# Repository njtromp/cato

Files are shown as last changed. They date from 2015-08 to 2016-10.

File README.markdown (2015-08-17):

# What's it all about
This project started slightly after I bought a sail boat, an Amigo 27 to be precisely.
At the time I bought the boat I did notice that the log (speed indicator) was not working
but that didn't bother me much. There where much, more important things, that needed my
attention. It is a mechanical VDO SumLog. There where two reasons for the log not to function.

1. a broken inner cable
2. a rusted impeller that does not turn

These two causes combined with the fact that replacement parts are hard to get your hands on
and the fact that I had a spare GPS Bluetooth dongle started me thinking. What if I can use
the GPS dongle for determining the speed and have a small (like a Raspberry PI) computer
control a electronic motor that drives the speed gauge?

## From RPM to knots and visa versa
I run some experiments using a cordless screwdriver for determining the RPM/knots settings.
It turned out to be about 100 RPM per knot :-). 

# Components
I needed some different components to get everything working

## Hardware
* a small computer
* a Bluetooth GPS dongle
* a USB Bluetooth dongle, for connecting the GPS to the computer
* a motor control unit that is capable of driving the electronic motor
* a electronic motor that is capable of runnning at 800-900 RPM with enough torque that will
be attached to the remainder of the inner cable
* a speed sensor for determining the RPM of the electronic motor (needed for feedback loop)

After some Googling and browsing the internet I come to the following shoppinglist:

* a Raspberry PI B+ (small, low power consumption, 4 USB ports, capable of running Debian)
* a small Bluetooth dongle
* a powerfull electro motor (capble of running at 13000 RPM and a torque of about 0.15 Nm)
* a AdaFruit PWM board based upon a PCA9685 chip
* a power mosfet that will be driven by the AdaFruit board and that will drive the engine
* a good old power transistor 2N3055 and a 12V zener-diode that will ensure that the voltage that
is supplied to the electro motor will stay constant and within the allowed range
* a IR photomicrosensor that can be used for detecting the RPM of the electro motor

I also bought a USB WiFi dongle that will be used for providing a small local WiFi network.  

## Software
* a program that reads the speed information from the GPS dongle and adjusts the speed of
the electronic motor

Although I am a Java Software Engineer by trade I wanted to use a language that has a smaller
memory footprint. After experimenting with Python and NodeJS I chose NodeJS. There are a
lot of modules available for it that integrate with GPSD for example. An other thing that I
like is the fact that the JavaScript is compiled to native code by the V8 engine prior to
running the code.

# Putting it all together
Back in highschool I played a lot around with electronic components and used a soldering iron
for repairing TVs, radios etc. so with I little luck I should still be able to get the
hardware connected. The software proved to be quite easy although being used to a statically
typed language is challenging a loosely typed language needs more trial and error then I am
used to. After some experimenting and using the soldering iron after 25 years I had a prototype
that seemed to be working. During the first trials I discovered that the electro motor was
having a difficult time working at low speeds, typically below 200-300 RPM.

## First improvements (dual power setting)
The problems at low RPMs are caused by the low duty-cycle of the PWM. In order to get the
duty-cycle up the engine must run using a lower voltage. Because I already was using a very
simple voltage stabilizing component (the 2N3055 and the zener-diode) it was relatively easy
to add a extra transistor and a second zener-diode (5V this time) to the existing voltage
stabilizing circuit. This change needed a software counterpart as well. The program must be
able to switch between the voltages at which the engine is running. In order to prevent the
system from switching back and forth between the two different power settings some sort of
delay was needed between the moment the first switch was needed and the actual switching.
The first trials with this new power switching module showed a flaw in the motorcontrol
program. When the power setting was switched from low voltage (5V) to high voltage (12V)
the engine initially was spinning at around 900 RPM (which is equal to 9 knots!) while
prior to the switch is was running at around 300 RPM. Within seconds this was corrected by
the feedback loop but it was not the behavior I wanted. Measuring the duty-cycle at low
voltage and high voltage with the some target RPM showed that there seems to be a 10 to 3
ratio between the duty-cycles. With the control program correcting the duty-cycle when
switching between the power settings lead to a small jitter that is for now within
acceptable ranges.  

## Second improvements (wireless instruments application)
As mentioned before I also bought a USB WiFi dongle. The purpose of this dongle is to have
the Raspberry PI act as a WiFi hotspot that should provide internet connection (through USB
tethering) to everybody on board as long as my phone as a proper internet connection.
Besides provinding internet access this lead to the idea of a small web application that
would use the GPS information for showing the speed and location on any connected device.

# Where to go next
Up till now everything seems to be working. Everything is still in beta phase but for me it
is working fine. Because I was not very familiar with NodeJS and used a whole lot of mixed
quality examples and made some wrong design decisions in the early stages of the project
the whole project needs a major overhaul.

## Code overhaul
* write my own NMEA handling/parsing. I haven't found a NodeJS module that handles NMEA
messages in a way I like (mind you that I am coming from a statically typed language).
* introduce a easier extensible software architecture (NMEA event bus)
* get rid of the tightly coupling between NMEA parsing, motor control, powerswitching and
the instruments application

# TODO
* add some pictures
* add some electronic diagrams
* log the NMEA message on the Raspberry PI for later usage by other applications, OpenCPN
for example

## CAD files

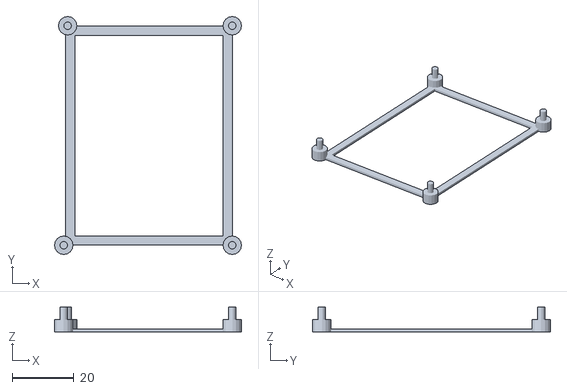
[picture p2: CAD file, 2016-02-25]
tinker/cato_log_controller_case.stl
60.6 x 77.1 x 8.00

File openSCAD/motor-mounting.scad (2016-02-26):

module raw_motor_support(width,depth,clearance,motorDiameter) {
	height = motorDiameter/2+clearance-0.5;
	difference() {
		cube([width,depth,height]);
		translate([width/2,0,motorDiameter/2+clearance]) {
			rotate([-90,0,0]) {
				$fn=64;
				cylinder(h=depth,d=motorDiameter);
			}
		}
	}
}

module nut_mount(nutDiameter,boltHeadDiameter,boltLength,boltDepth) {
	translate($fn=64,[0,0,boltDepth]) cylinder(boltLength, d=nutDiameter);
	cylinder($fn=6,boltDepth, d=boltHeadDiameter);
}

module bolt_mount(boltDiameter,boltHeadDiameter,boltLength,boltDepth) {
	$fn=64;
	translate([0,0,boltDepth]) cylinder(boltLength, d=boltDiameter);
	cylinder(boltDepth, d=boltHeadDiameter);
}

module upper_support() {
	difference() {
		raw_motor_support(width,depth,clearance,motorDiameter);
		translate([10,depth/2,0]) bolt_mount(boltDiameter+0.5,boltHeadDiameter+0.5,boltLength,boltDepth);
		translate([width-10,depth/2,0]) bolt_mount(boltDiameter+0.5,boltHeadDiameter+0.5,boltLength,boltDepth);
	}
}

module lower_support() {
	difference() {
		raw_motor_support(width,depth,clearance,motorDiameter);
		translate([10,depth/2,0]) nut_mount(boltDiameter+0.5,nutDiameter+0.5,boltLength,boltDepth);
		translate([width-10,depth/2,0]) nut_mount(boltDiameter+0.5,nutDiameter+0.5,boltLength,boltDepth);
	}
}

width=60;
depth=25;
clearance=10;
motorDiameter=32;
boltDiameter=3;
boltHeadDiameter=6;
nutDiameter=8;
boltLength=10;
boltDepth=motorDiameter/2+clearance-boltLength;

lower_support();
translate([width,0,motorDiameter +2*clearance]) rotate([0,180,0]) upper_support();

// difference(){
// 	translate([-2*clearance,-2*clearance,-clearance]) {
// 		cube([width+4*clearance,depth+4*clearance,clearance]);
// 	}
// }

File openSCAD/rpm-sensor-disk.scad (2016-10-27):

module pie_slice(thickness,innerRadius,outerRadius,angle) {
	$fn=64;
	difference() {
		intersection() {
			cylinder(h=thickness, r=outerRadius, center=false);
			cube([outerRadius,outerRadius,thickness],false);
	    	rotate(angle-90) cube([outerRadius,outerRadius,thickness],false);
		}
    	cylinder(h=thickness, r=innerRadius, center=false);
	}
}

module rpm_disk(thickness,axeRadius,nodgeIndent,outerRadius,innerRadius,wingCount) {
	$fn=30;
	// Create hole for axis
	difference() {
		cylinder(thickness, r=innerRadius);
		cylinder(thickness, r=axeRadius);
	}
	// Correction for nodge
	translate([axeRadius-nodgeIndent, -axeRadius, 0]) {
		cube([axeRadius, 2*axeRadius, thickness]);
	}

	// Place 'wings'
	for(angle = [0: 360/wingCount : 359]) {
		rotate(angle) {
			pie_slice(thickness,innerRadius-0.5,outerRadius,180/wingCount);
		}
	}
}

rpm_disk(3,3,0.5,20,10,6);

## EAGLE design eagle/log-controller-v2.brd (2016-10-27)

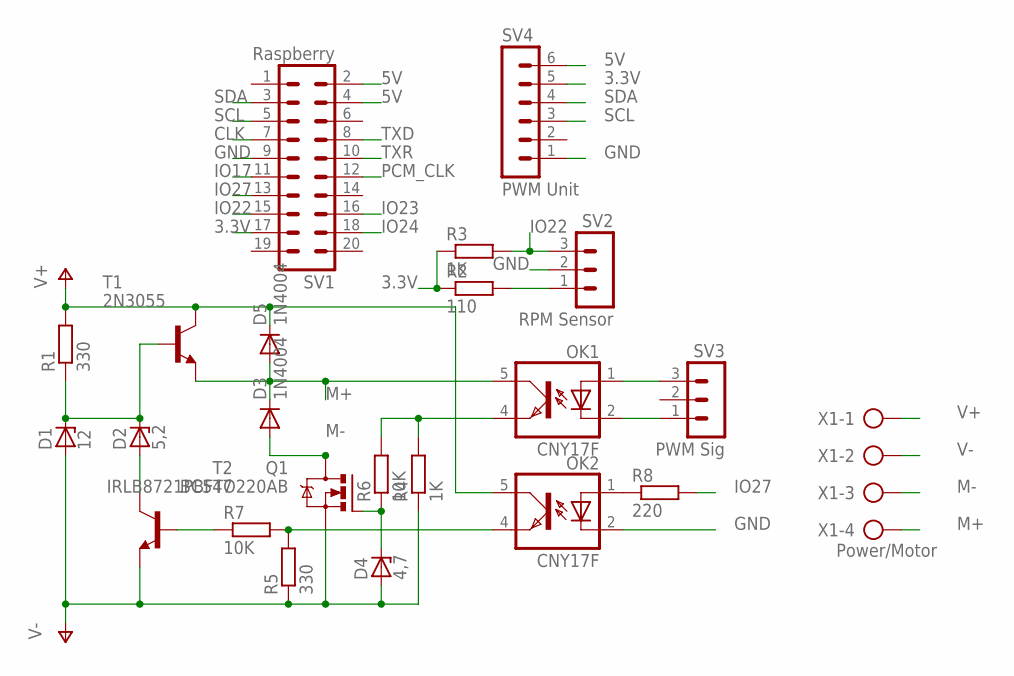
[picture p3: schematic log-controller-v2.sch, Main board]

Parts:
D1: 12; DO34Z7
D2: 5,2; DO34Z7
D3, D5: 1N4004; DO41-10
D4: 4,7; DO34Z7
OK1, OK2: CNY17F; DIL06
Q1: IRLB8721PBFTO220AB; TO220AB
R1, R5: 330; 0207/12
R2: 110; 0207/10
R3: 1K; 0207/10
R4: 1K; 0207/12
R6, R7: 10K; 0207/12
R8: 220; 0207/10
SV1: Raspberry; MA10-2
SV2: RPM Sensor; MA03-1
SV3: PWM Sig; MA03-1
SV4: PWM Unit; MA06-1
T1: 2N3055; TO3
T2: BC547; TO92
X1: Power/Motor; AK300/4

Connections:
3.3V: R2.1, R3.1, SV1.17, SV4.5
5V: SV1.2, SV1.4, SV4.6
CLK: SV1.7
GND: OK2.2 (C), SV1.9, SV2.2, SV4.1
IO17: SV1.11
IO22: R3.2, SV1.15, SV2.3
IO23: SV1.16
IO24: SV1.18
IO27: R8.2, SV1.13
M+: D3.C, D5.A, OK1.5 (COL), T1.E, X1.4
M-: D3.A, Q1.D, X1.3
unnamed: D1.C, D2.C, R1.1, T1.B
unnamed: D2.A, T2.3 (C)
unnamed: OK1.4 (EMIT), R4.2, R6.2
unnamed: R2.2, SV2.1
unnamed: OK1.1 (A), SV3.3
unnamed: OK1.2 (C), SV3.1
unnamed: OK2.4 (EMIT), R5.2, R7.2
unnamed: R7.1, T2.2 (B)
unnamed: D4.C, Q1.G, R6.1
unnamed: OK2.1 (A), R8.1
PCM_CLK: SV1.12
SCL: SV1.5, SV4.3
SDA: SV1.3, SV4.4
TXD: SV1.8
TXR: SV1.10
V+: D5.C, OK2.5 (COL), R1.2, T1.C, T1.C/ (C), X1.1
V-: D1.A, D4.A, Q1.S, R4.1, R5.1, T2.1 (E), X1.2

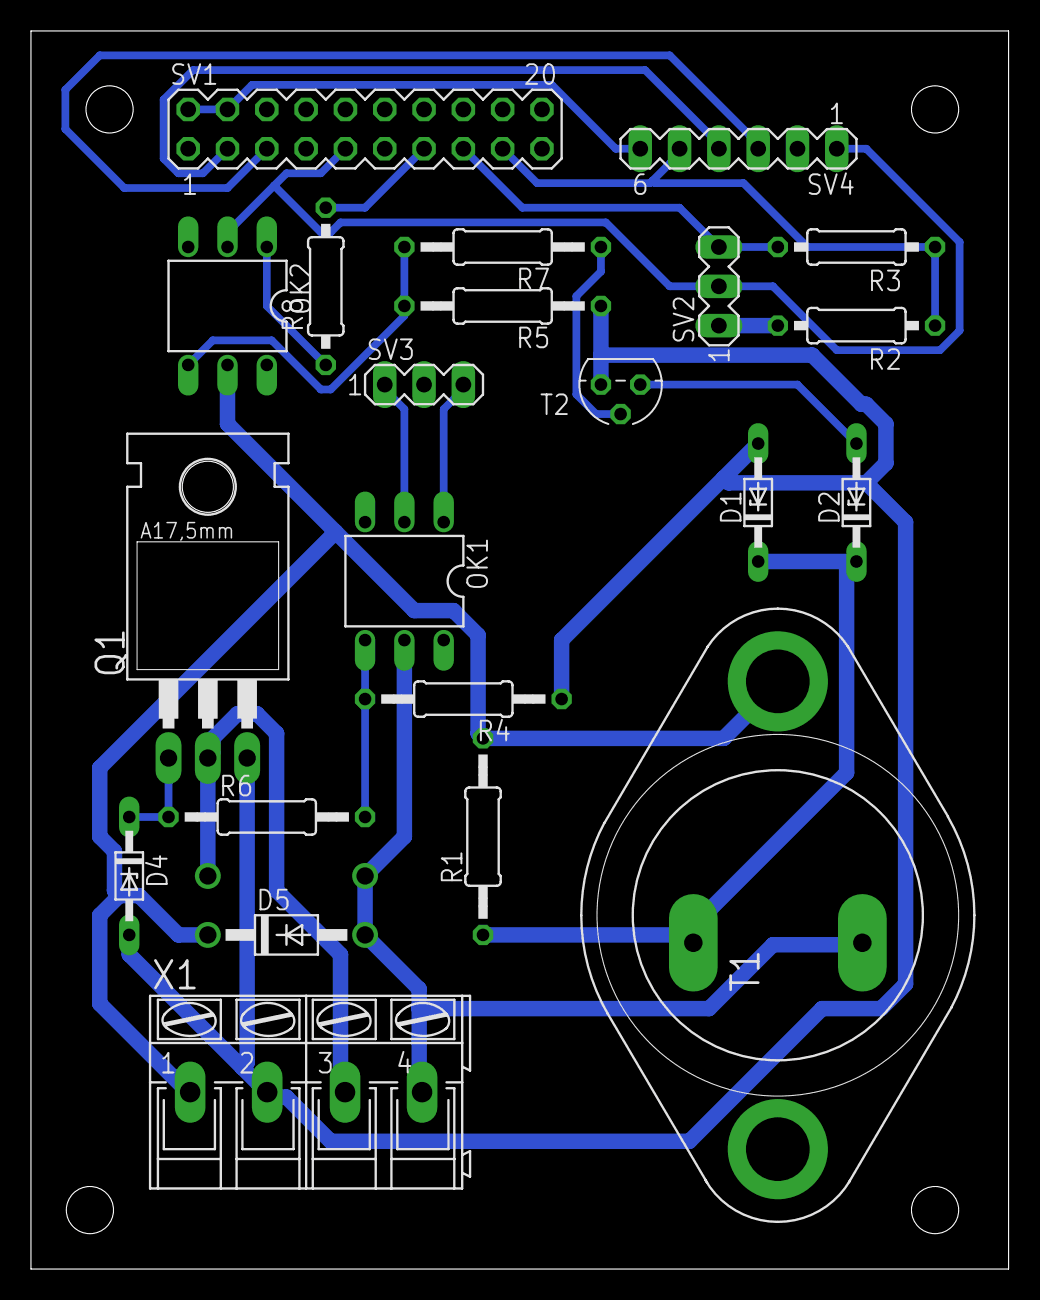
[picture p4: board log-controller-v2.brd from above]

Board: 2 copper layers, 63.2 x 80.0 mm, 23 parts (1 on the bottom side), 21 nets.

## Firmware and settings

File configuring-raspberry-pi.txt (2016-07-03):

# Configuring Raspberry PI

# Use the RasPI config tool to enable I2C and serial support
sudo raspi-config

# Basicaaly I followed this tutorial
# https://learn.adafruit.com/setting-up-a-raspberry-pi-as-a-wifi-access-point/install-software
# https://learn.adafruit.com/adafruit-ultimate-gps-on-the-raspberry-pi/setting-everything-up

# The next could be needed when starting the rasp-config tools complains about no language has been set
cat << 'EOF' >> /etc/default/locale
LANG=en_US.UTF-8
LANGUAGE=en_US.UTF-8
LC_ALL=en_US.UTF-8
EOF

# Here is the real installation :-)

# Install dnsmasq
sudo apt-get install dnsmasq

#Configure DNS DHCP (dnsmasq)
# Change or add to the bottom of the configuration fiel
cat << 'EOF' >> /etc/dnsmasq.conf
interface=eth0
interface=wlan0
no-hosts
addn-hosts=/etc/hosts.dnsmasq
dhcp-range=192.168.66.20,192.168.66.150,24h
dhcp-range=192.168.99.20,192.168.99.150,24h
dhcp-option=6,192.168.66.10
dhcp-option=6,192.168.99.10
EOF

# Make the Raspberry PI known on two differen names
cat << 'EOF' > /etc/hosts.dnsmasq
192.168.66.10 cato
192.168.99.10 cato-wired
EOF

# Install hostapd for Raspberry PI
sudo apt-get install hostapd

# Configure hostapd
# Configure the access point
cat << 'EOF' >> /etc/hostpad/hostapd.conf
# Basic configuration
interface=wlan0
ssid=cato
channel=6
hw_mode=g
country_code=NL

# WPA and WPA2 configuration
macaddr_acl=0
ignore_broadcast_ssid=0
wpa=2
wpa_passphrase=<dat mag je niet weten!>
wpa_key_mgmt=WPA-PSK
wpa_pairwise=CCMP
rsn_pairwise=CCMP
EOF

# Enable the accesspoint
cat << 'EOF' >> /etc/default/hostapd
DAEMON_CONF="/etc/hostapd/hostapd.conf"
EOF

# Enable forwarding in the kernel permanent
# sudo vi /etc/sysctl.conf
# Search near the end
# net.ipv4.ip_forward=1

# and for now
sudo sh -c "echo 1 > /proc/sys/net/ipv4/ip_forward"

# Configure the iptables
sudo iptables -t nat -A POSTROUTING -o usb0 -j MASQUERADE 
sudo iptables -A FORWARD -i usb0 -o wlan0 -m state --state RELATED,ESTABLISHED -j ACCEPT
sudo iptables -A FORWARD -i wlan0 -o usb0 -j ACCEPT
sudo iptables -A FORWARD -i usb0 -o eth0 -m state --state RELATED,ESTABLISHED -j ACCEPT
sudo iptables -A FORWARD -i eth0 -o usb0 -j ACCEPT
# Save the configuration
sudo sh -c "iptables-save > /etc/network/iptables.forward.nat"

# And activate the configuration after each reboot
cat << 'EOF' >> /etc/network/interfaces
up iptables-resotre < /etc/network/iptables.forward.nat
EOF

# Install GPSD daemon and some tools
sudo apt-get install gpsd gpsd-clients

# Remove 'console=ttyAMA0,115200' and 'kgdboc=ttyAMA0,115200' if present from /boot/cmdline.txt

# Disable some serial services
sudo systemctl mask serial-getty@ttyAMA0.service

# Create startup script for the gpsd service
cat << 'EOF' > start-gps
#!/bin/bash
sudo /usr/sbin/gpsd -n -G -F /var/run/gpsd.sock /dev/ttyAMA0
EOF
chmod +x start-gpsd
 
# Addd the next line to 'crontab -e'
@reboot /home/pi/start-gpsd

# Start the GPSD daemon
# -G listen on all interfaces
# -n don't wait for clients to connect (start polling the GPS immediately)
# gpsd -G -n /dev/ttyAMA0

# Check if everything is working properly (Optional)
# gpsmon /dev/ttyAMA0

# Enable i2c interface
sudo apt-get install i2c-tools

# Activate I2C modules and configuration
cat << 'EOF' >> /etc/modules
i2c-bcm2708 
i2c-dev
EOF

# Only if not present, so check first!
#cat << 'EOF' >> /boot/config.txt
#dtparam=i2c1=on
#dtparam=i2c_arm=on
#EOF

# Install nodejs
curl -sLS https://apt.adafruit.com/add | sudo bash
sudo apt-get install node
# This gives a segfault :-(
#curl -sL https://deb.nodesource.com/setup_6.x | sudo -E bash -
#sudo apt-get install nodejs

# The next lines might not be needed but unable to verify at this moment
#sudo apt-get install python-smbus
#sudo chmod o+rw /dev/i2c*

# The next lines might not be needed but unable to verify at this moment
# Only needed when running 'gcc' results in a 'unknown program/command'
# Version numbers might be different!
#sudo apt-get install gcc-4.8 g++-4.8
#sudo update-alternatives --install /usr/bin/gcc gcc /usr/bin/gcc-4.8 60 --slave /usr/bin/g++ g++ /usr/bin/g++-4.8
#sudo update-alternatives --install /usr/bin/gcc gcc /usr/bin/gcc-4.9 40 --slave /usr/bin/g++ g++ /usr/bin/g++-4.9
#sudo update-alternatives --config gcc 

# Install used modules
npm install node-gpsd onoff keypress socket.io nmea-0183
# Due to some error during building lets use a previous version
npm install i2c@0.2.1

# Install Apache HTTPD
sudo apt-get install apache2
sudo a2enmod proxy
sudo a2enmod proxy_http

# Add reverse proxy configuration after the last <Directory> element
# sudo vi /etc/apache2/sites-enabled/000-default
#        ProxyPass / http://cato:8080/ retry=0
#        ProxyPassReverse / http://cato:8080/ 
# And restart Apache
# sudo service apache2 restart

# Add the following line to 'crontab -e'
@reboot /home/pi/start-nodejs

# Create (sym)links to 'start-gpsd' and 'start-nodejs' in the home folder.

sudo reboot

# RPM 299, 5V  => Offstep = 1900
# RPM 301, 12V => Offstep = 565

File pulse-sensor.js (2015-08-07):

/**
 * This module measures the pulselength of a IR sensor that detects the rotation
 * of a disc (whith intermitted holes) that is attached to a electronic motor. 
 */

"use strict";

var Gpio = require('onoff').Gpio;

/**
 * Starts a new sensor. 
 *
 * @param: config has two properties.
 * - sensorPin: the GPIO pin number to which the pulse sensor is attached.
 * - activeLevel: the level (0 or 1) which is considered as the start of a new pulse. 
 *
 * @param: pulseCallback (optional) function is called on every pulse. This method takes a single
 * parameter that will have the value of the pulselength in nanoseconds of the last pulse.
 */
function PulseSensor(config, pulseCallback) {
  console.log('Installing RPM sensor listener.');
  this.pulseCallback = typeof pulseCallback === "function" ? pulseCallback : function(pulseLengthInNanos) { return; };
  this.sensorPin = config.sensorPin;
  this.activeLevel = config.activeLevel;
  this.lastSwitch = -1;
  this.pulses = new Array();
  
  this.sensor = new Gpio(config.sensorPin, 'in', 'both');
  var _this = this;
  this.sensor.watch(function(err, value) {
    _this.registerPulse(value)
  });
}

/**
 * Retuns the average pulse length of the pulses since the
 * last call to this function. The pulse length is in nanosecods.
 * A value of -1 indicates that no pulse has been detected since
 * the previous pulse!
 */
PulseSensor.prototype.getAveragePulseLength = function() {
  if (this.pulses.length == 0) {
    return -1;
  } else {
    var copyOfPulses = this.pulses.splice(0, this.pulses.length);
    return averagePulseLength(copyOfPulses);
  }
}

/**
 * Adds new pulse to the set of pulses and calls the pulseCallback function.
 */
PulseSensor.prototype.registerPulse = function(value) {
  if (value == this.activeLevel) {
    var currentSwitch = convertNanoTimeData(process.hrtime());
    if (this.lastSwitch != -1) {
      var pulseLengthInNanos = currentSwitch - this.lastSwitch;
      this.pulses.push(pulseLengthInNanos);
      this.pulseCallback(pulseLengthInNanos);
    }
    this.lastSwitch = currentSwitch;
  }
}

/**
 * Converts the nano-second time construct (from process.hrtime()) into a single value.
 */
function convertNanoTimeData(nanoTimeData) {
  return (nanoTimeData[0] * 1000000000) + nanoTimeData[1];
} 

/**
 * Returns the average pulse length of the pulses present in copyOfPulses.
 */
function averagePulseLength(copyOfPulses) {
  var sum = 0;
  for (var i = 0; i < copyOfPulses.length; i++) {
    sum += copyOfPulses[i];
  }
  return sum / copyOfPulses.length;
}

module.exports = PulseSensor;

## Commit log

2015-03-13 Switched to better structure of the code
2015-03-13 Added shutdown button via Node.js :-)
2015-03-14 Added jitter detection.
2015-03-18 Implementing own motor control. The PCA9685 module contains errors and has some timing issues that need to be handled.
2015-03-18 Looping through led dim cycle.
2015-03-29 Trying to switch to nano seconds....
2015-03-29 Using millseconds for RPM sensor.
2015-03-29 Displaying milliseconds for every 1/6th rotation.
2015-03-30 RPM sensor will be used by another module, not by Cato directly
2015-04-05 Refactored the motor and pwm modules.
2015-04-06 Sensor is working.
2015-04-07 Refactored code so the global THIS variable is no longer needed.
    [pulse-sensor.js]
2015-04-07 Tweaked motor control so it is able to drop the RPM till 100.
2015-04-07 Renamed motor to rpm-controller.
2015-04-08 Added calibration module.
2015-04-08 Scaffolding for calibration done.
2015-04-08 Calibration should be working.
2015-04-08 Restructed the calibration configuration.
2015-04-08 Switched to actual working version.
    The previous ones had some 'require' lines placed as comments.
2015-04-09 Fixed issues that prevented 'calibrate' not to function.
    [factory.js]
2015-04-17 Added some comment and prevented a compilation error.
    [factory.js]
2015-04-25 First 'real' calibration settings.
2015-06-05 Added configuration document and updated comments in some files.
    [configuring-raspberry-pi.txt]
2015-06-07 Added more installation instructions.
    [configuring-raspberry-pi.txt]
2015-06-07 Multiple changes / improvements
    - Added a powerswitch that makes it possible to keep de duty cycle relatively high for the same RPM by limiting the voltage for the motor.
    - Added a calculator that can calculate the distance and based on two positions
    - Converted some hardcoded values into configuration items.
2015-06-10 Introduced limiting the voltage for the electronic engine when running at low RPM (currently < 300 RPM).
    And moved more settings into the 'config.json' file.
    [configuring-raspberry-pi.txt]
2015-06-11 Corrected device name to match current setup
2015-06-11 Added some more installation instructions.
    [configuring-raspberry-pi.txt]
2015-06-12 Updated installation instructions
    [configuring-raspberry-pi.txt]
2015-06-15 Started hostapd and dnsmasq instructions
    [configuring-raspberry-pi.txt]
2015-06-17 Added some documents about configuring a Raspberry PI to become accesspoint
2015-06-18 Started taking care of the TODOs
    [configuring-raspberry-pi.txt]
2015-06-23 Made de handling for HTML files a little smarter and introduced a second speed gauge.
2015-07-19 Some more tests for stabilising the WiFi connection.
    [configuring-raspberry-pi.txt]
2015-07-19 Adjusted according to actual settings.
    [configuring-raspberry-pi.txt]
2015-07-21 Calibration info for current setup.
2015-07-30 Attempting to cope more gentle with voltage switching. Currently the motor spins either out of control or comes to a dead stop when switching.
    [configuring-raspberry-pi.txt]
2015-07-30 Added config for improved voltage switching.
2015-07-30 Debugged and improved the voltage switching behaviour!
2015-08-09 Integrated the server with the existing code.
    Very rough. Needs a complete overhaul.
    [configuring-raspberry-pi.txt]
2015-08-10 Added some info on installing and configuring Apache2 as a reverse proxy.
    [configuring-raspberry-pi.txt]
2015-08-13 Some small improvements
    [configuring-raspberry-pi.txt]
2016-02-09 More datasheets added and removed a feature (the reset/shutdown button) that is not needed any more.
2016-02-17 Corrected a problem when the battery is running low and a transition is made to run in lose-power mode.
2016-02-17 Preparation for the new PCB. On this new PSB the power switch is connected to GPIO27.
2016-02-25 Sample for 3D printing a case.
    Just contains the mounting points for the log controller.
    [cato_log_controller_case.stl]
2016-02-25 Playing with OpenSCAD to create a better RPM sensor disk.
    [first-attempt.scad]
2016-02-25 Looking good.
    [first-attempt.scad]
2016-02-25 Final prototype. Already printed :-)
    [rpm-sensor-disk.scad]
2016-02-25 Result of a small error, should have been renamed to 'rpm-sensor-disk'.
    [first-attempt.scad]
2016-02-26 Made more flexible.
    [rpm-sensor-disk.scad]
2016-02-26 Renamed some parameters and move some comments around.
    [rpm-sensor-disk.scad]
2016-02-26 Converted into module.
    [rpm-sensor-disk.scad]
2016-02-26 Added PCB and electronic schema.
    [log-controller-v2.brd, log-controller-v2.sch]
2016-02-26 Started with motor mount design.
    [motor-mounting.scad]
2016-06-26 Corrected case-error, looks like Math.Min does not exist. Math.min should be the correct.
2016-06-27 Added a lot of installation inforamtion.
    [configuring-raspberry-pi.txt]
2016-06-27 Added pin layout picture
2016-06-27 Rearranged instructions.
    [configuring-raspberry-pi.txt]
2016-06-27 Preparing for the Adafruit Ultimate GPS module.
    [configuring-raspberry-pi.txt]
2016-06-29 Updated installation instructions with Adafruit GPS module and NTPD/GPSD.
    [configuring-raspberry-pi.txt]
2016-06-30 Looks like everything startup at boot.
    [configuring-raspberry-pi.txt]
2016-06-30 Finalizing the setup.
    [configuring-raspberry-pi.txt]
2016-07-03 Added some Apache confgiruation to ensure a better experience.
    [configuring-raspberry-pi.txt]
2016-07-03 Down graded to node v0.12.6.
    The Raspberry PI is running this version so it must be compatible with
    v0.12.6!
2016-10-27 Al lot of changes from a couple of month ago, don't know exactly what and why.
2016-10-27 Some small fixes, mainly layout.
    [rpm-sensor-disk.scad]
2016-10-27 Changed a resistor due to the electronic gearbox not working.
    Seems not to have solved it completely... back to the drawing board.
    [log-controller-v2.brd, log-controller-v2.sch]
